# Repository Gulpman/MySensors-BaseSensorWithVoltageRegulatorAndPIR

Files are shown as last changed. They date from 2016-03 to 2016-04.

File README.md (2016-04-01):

# MySensors-BaseSensorWithVoltageRegulatorAndPIR
A battery powerd (CR123A) basic sensor with onboard PIR mounting and voltage regulator to 3.3V

This is my first own eagle project.

<h1>What's on the sensor?</h1>
<ul>
<li>ATMega 328P-AU</li>
<li>NRF24L01+ SMD version</li>
<li>AT25DF512C-SSHN-B EEPROM (512k) (optional)</li>
<li>ATSHA204A (optional)</li>
<li>PIR Sensor 3.3V (optional)</li>
<li>MAX1724+ (optional - if you do not want to use it shorten jumper SJ2)</li>
<li>I2C header with (optional) Pullups</li>
	<ul>
        <li>PIN layout allows to directly connect standard breakout boards for BMPx80 or Si7021</li>
    </ul>
<li>FTDI header</li>
	<ul>
        <li>As I used the Sparkfun headers the FTDI header can just be pulled in and does not have to be soldered (hopefully, never tried it out :) )</li>
    </ul>
<li>ISP header</li>
<li>CR123A battery holder</li>
<li>The following pins can be used via pin headers</li>
    <ul>
        <li>A1 to A2</li>
        <li>D3 to D6</li>
    </ul>
</ul>

Jumper SJ1 is useless at the moment - the idea behind it is that, dependent on the battery level the SHDN pin of the MAX 1724 could be set to low or high by the sketch running on the 328P. Help and hints for implementing this are highly appreciated. :)

The PCB is meant to fit into an ABS82 case. The ABS-82 is for example available at TME -> <a href="http://www.tme.eu/de/details/abs-82/universal-gehaeuse/">ABS-82 @ TME</a>. 

Big kudos go to Omega-5 from forum.fhem.de who had an eye on my first steps in the Eagle world and who is responsible at least for a few of the capacitors and their position very close to the 328P :)
I think I can admit that this sensor would have had no chance to function without him having a look on my files.

After the sensor has proven that it is functioning the next version will have the following improvements:
<ul>
<li>Smaller - PIR sensor will not be mounted onboard. Makes it cheaper to produce as well as more flexible.</li>
<li>Implementation of SJ1 - allow the sketch to shutdown the MAX 1724 if voltage of the battery is high enough.</li>
<li>Optional pullups for digital and anolog pins</li>
</ul>

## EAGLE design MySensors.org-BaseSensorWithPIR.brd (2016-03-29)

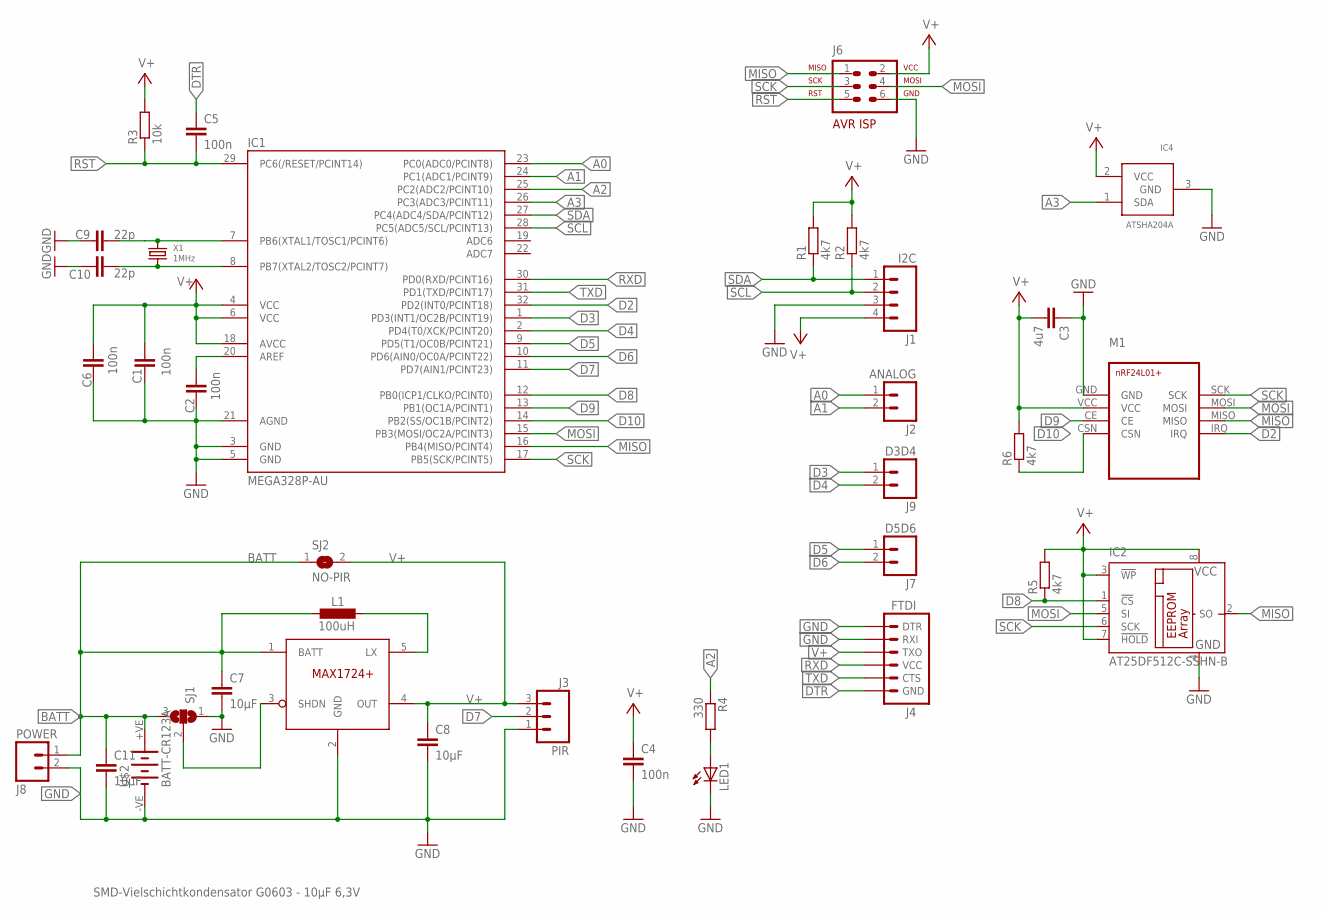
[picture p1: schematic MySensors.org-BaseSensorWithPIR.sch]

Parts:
C1, C2, C4, C5, C6: 100n; C0603
C3: 4u7; C0603
C7, C8, C11: 10µF; C0603
C9, C10: 22p; C0603
IC1: MEGA328P-AU; TQFP32-08
IC2: AT25DF512C-SSHN-B; SO-08
IC4: ATSHA204A; SOT23
J1: I2C; 1X04_LOCK
J2: ANALOG; 1X02
J3: PIR; 1X03_LOCK
J4: FTDI; 1X06_LOCK
J6: N/M; AVR-ISP-6
J7: D5D6; 1X02
J8: POWER; 1X02
J9: D3D4; 1X02
L1: 100uH; 1212FPS
LED1: LEDSML0603; SML0603
M1: NRF24L01+NRF24L01+MINI; NRF24L01+MINI
R1, R2, R5, R6: 4k7; R0603
R3: 10k; R0603
R4: 330; R0603
SJ1: SJ2W; SJ_2
SJ2: NO-PIR; SJ
STEPUP: MAX1724; SOT23-5L
U$2: BATT-CR123A; KEYSTONE-2/3A
X1: 1MHz; 2P-L3.2XW1.5MM

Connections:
A0: IC1.23 (PC0(ADC0/PCINT8)), J2.1
A1: IC1.24 (PC1(ADC1/PCINT9)), J2.2
A2: IC1.25 (PC2(ADC2/PCINT10)), R4.1
A3: IC1.26 (PC3(ADC3/PCINT11)), IC4.1 (SDA)
BATT: C7.1, C11.1, J8.1, L1.1, SJ1.3, SJ2.1, STEPUP.1 (BATT), U$2.+VE (+)
D2: IC1.32 (PD2(INT0/PCINT18)), M1.IRQ
D3: IC1.1 (PD3(INT1/OC2B/PCINT19)), J9.1
D4: IC1.2 (PD4(T0/XCK/PCINT20)), J9.2
D5: IC1.9 (PD5(T1/OC0B/PCINT21)), J7.1
D6: IC1.10 (PD6(AIN0/OC0A/PCINT22)), J7.2
D7: IC1.11 (PD7(AIN1/PCINT23)), J3.2
D8: IC1.12 (PB0(ICP1/CLKO/PCINT0)), IC2.1 (!CS), R5.1
D9: IC1.13 (PB1(OC1A/PCINT1)), M1.CE
D10: IC1.14 (PB2(SS/OC1B/PCINT2)), M1.CSN, R6.1
DTR: C5.1, J4.6 (GND)
GND: C1.2, C2.2, C3.1, C4.2, C6.2, C7.2, C8.2, C9.2, C10.2, C11.2, IC1.3 (GND), IC1.5 (GND), IC1.21 (AGND), IC2.4 (GND), IC4.3 (GND), J1.3, J3.1, J4.1 (DTR), J4.2 (RXI), J6.6, J8.2, LED1.C, M1.GND, SJ1.1, STEPUP.2 (GND), U$2.-VE (-)
LX: L1.2, STEPUP.5 (LX)
MISO: IC1.16 (PB4(MISO/PCINT4)), IC2.2 (SO), J6.1, M1.MISO
MOSI: IC1.15 (PB3(MOSI/OC2A/PCINT3)), IC2.5 (SI), J6.4, M1.MOSI
unnamed: LED1.A, R4.2
unnamed: C2.1, IC1.20 (AREF)
RST: C5.2, IC1.29 (PC6(/RESET/PCINT14)), J6.5, R3.1
RXD: IC1.30 (PD0(RXD/PCINT16)), J4.4 (VCC)
SCK: IC1.17 (PB5(SCK/PCINT5)), IC2.6 (SCK), J6.3, M1.SCK
SCL: IC1.28 (PC5(ADC5/SCL/PCINT13)), J1.2, R2.1
SDA: IC1.27 (PC4(ADC4/SDA/PCINT12)), J1.1, R1.1
SHDN: SJ1.2, STEPUP.3 (SHDN)
TXD: IC1.31 (PD1(TXD/PCINT17)), J4.5 (CTS)
V+: C1.1, C3.2, C4.1, C6.1, C8.1, IC1.4 (VCC), IC1.6 (VCC), IC1.18 (AVCC), IC2.3 (!WP), IC2.7 (!HOLD), IC2.8 (VCC), IC4.2 (VCC), J1.4, J3.3, J4.3 (TXO), J6.2, M1.VCC, R1.2, R2.2, R3.2, R5.2, R6.2, SJ2.2, STEPUP.4 (OUT)
XTAL1: C9.1, IC1.7 (PB6(XTAL1/TOSC1/PCINT6)), X1.2
XTAL2: C10.1, IC1.8 (PB7(XTAL2/TOSC2/PCINT7)), X1.1

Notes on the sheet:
SMD-Vielschichtkondensator G0603 - 10µF 6,3V

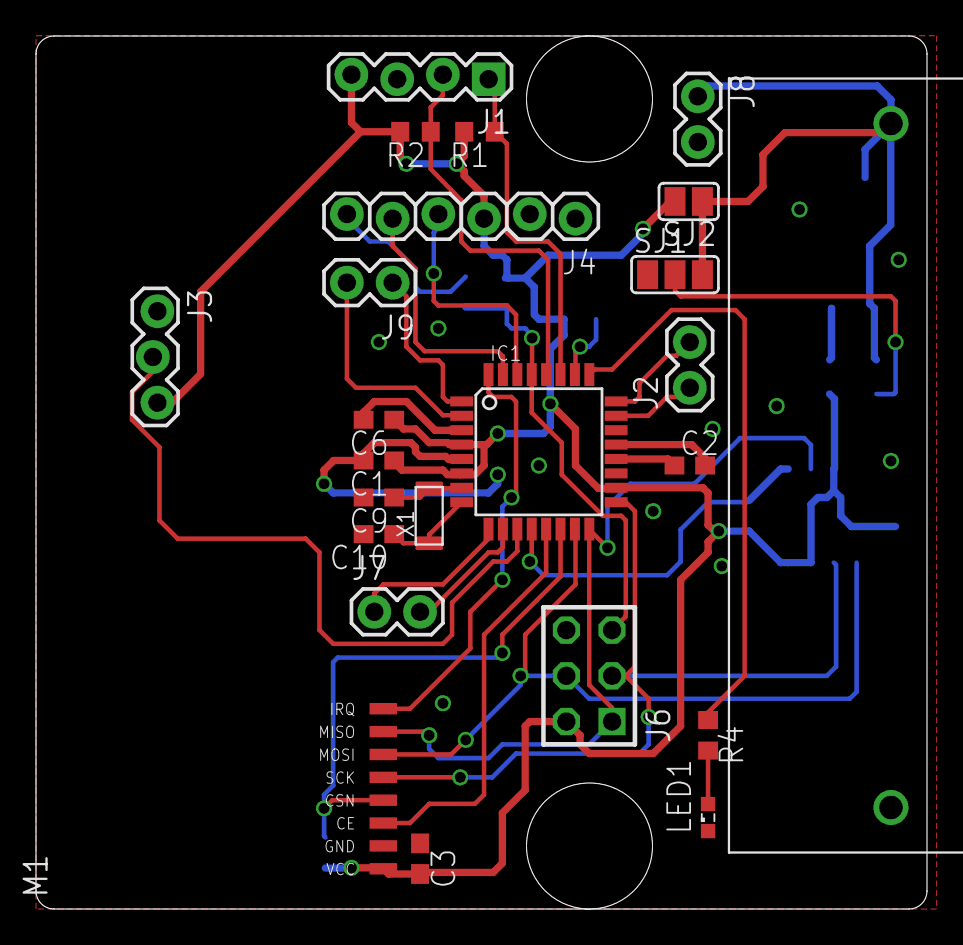
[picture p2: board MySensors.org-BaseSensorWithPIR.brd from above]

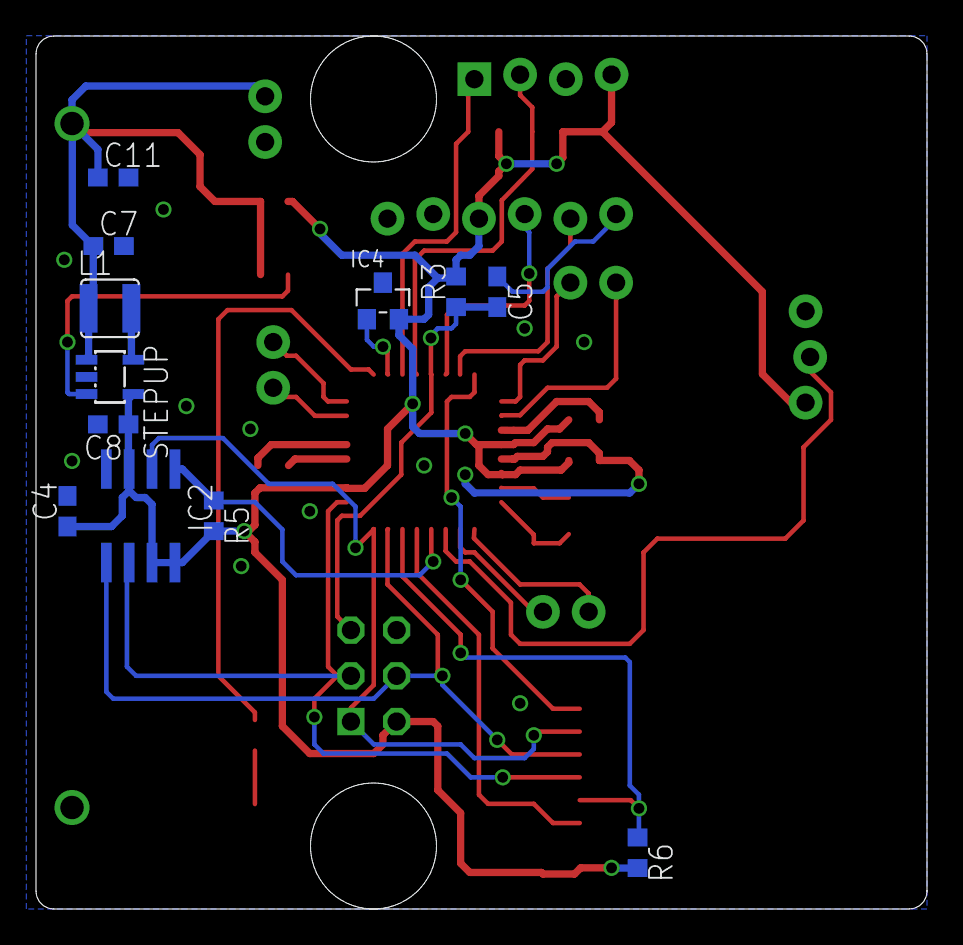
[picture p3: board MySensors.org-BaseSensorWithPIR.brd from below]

Board: 2 copper layers, 49.5 x 48.5 mm, 36 parts (12 on the bottom side), 31 nets.

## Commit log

2016-03-29 Added Eagle Schematics and Board
    [MySensors.org-BaseSensorWithPIR.brd, MySensors.org-BaseSensorWithPIR.sch]
2016-04-01 - some aesthetic corrections in the schema: - positive voltages are now all alligned upright - D10 label is directly connected to the electrical wire (there was a space in between before)
    [MySensors.org-BaseSensorWithPIR.sch]

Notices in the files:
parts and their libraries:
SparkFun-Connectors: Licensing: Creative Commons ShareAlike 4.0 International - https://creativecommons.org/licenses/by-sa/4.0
